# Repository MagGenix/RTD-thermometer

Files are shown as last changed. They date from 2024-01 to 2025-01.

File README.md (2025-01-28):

# RTD-Thermometer
Sreenivas Eadara

## Capabilities
This device can log temperatures down to .03125C using a PT100 probe and takes measurements every 110-120 ms. Measurements are streamed over USB serial (using the RP2040's USB-C port) and stored to a USB-A (plugged in to the USB Host port of the RP2040).

## Summary

This is a data logger built using the following parts from Adafruit:

Microcontroller: Feather RP2040 with USB Type A Host
https://www.adafruit.com/product/5723

Display: OLED FeatherWing
https://www.adafruit.com/product/4650

RTD Amplifier: MAX31865 PT100
https://www.adafruit.com/product/3328

RTD: 3 Wire PT100
https://www.adafruit.com/product/3290

PCB: Mint tin size Perma-Proto
https://www.adafruit.com/product/723

Using these parts just made it easier to finish the project (as opposed to spending time / revisions making my own modules), though there are plenty of other components that could work with modifications to the provided Arduino code.

Assembly involved wiring the MAX31865 to the default SPI pins on the RP2040 USB Host and stacking the OLED on the microcontroller through the perma-proto board. Note that depending on the PT100 probe used, traces may need to be cut and/or jumpers may need to be soldered on the MAX31865 breakout board. Please see Adafruit's instructions for this.

I designed a case to fit the device I built. If it helps, files (STEP and 3MF) are supplied with this repository. I powered the device using a LiPo battery from Adafruit so it could be used for a couple hours away from a charger (i.e. during experiments).

**See the LICENSE file in the CASE folder, which accompanies the STEP and 3MF files for the case, for information on the hardware copyright and licensing**

## Code
This code heavily uses examples and libraries from Adafruit's TinyUSB library and MAX31865 library (as well as the SH110X library for the display)!
It implements a state machine on Core 1 that controls the display and measures temperatures using the MAX31865, while Core 2 and the PIOs are responsible for USB host.

**See the LICENSE file in the FIRMWARE folder, which accompanies the code, for details on the code copyright and licensing.**

## Photos
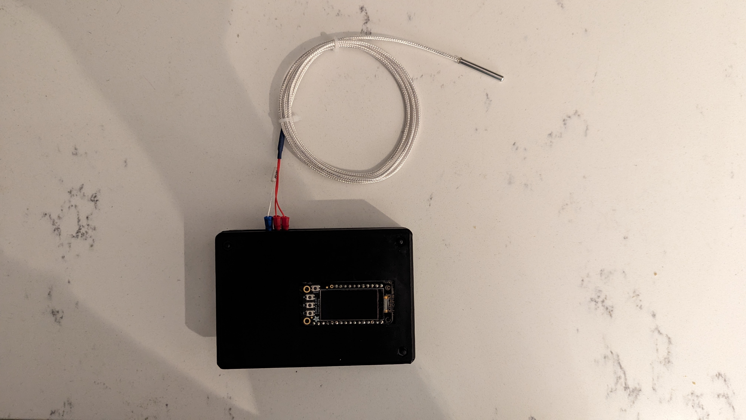
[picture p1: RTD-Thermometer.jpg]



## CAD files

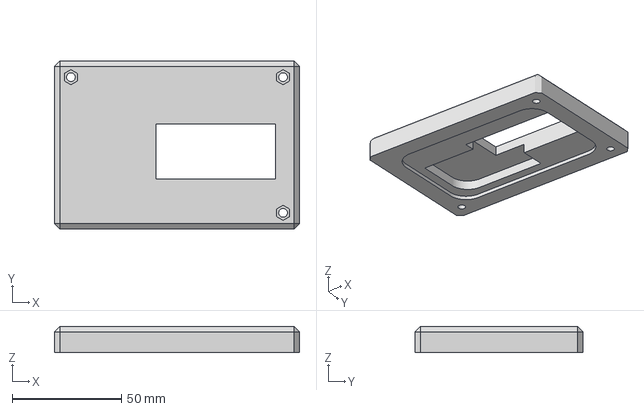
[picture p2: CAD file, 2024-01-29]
CASE/RTD-CASE - TOP.3mf
112.0 x 77.0 x 12.0 mm

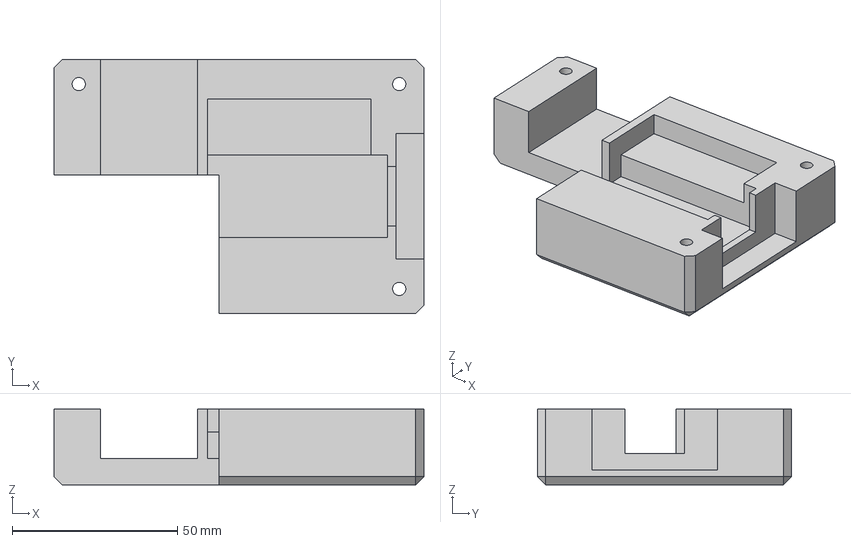
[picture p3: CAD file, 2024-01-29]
CASE/RTD-CASE - BOTTOM.3mf
112.0 x 77.0 x 23.0 mm

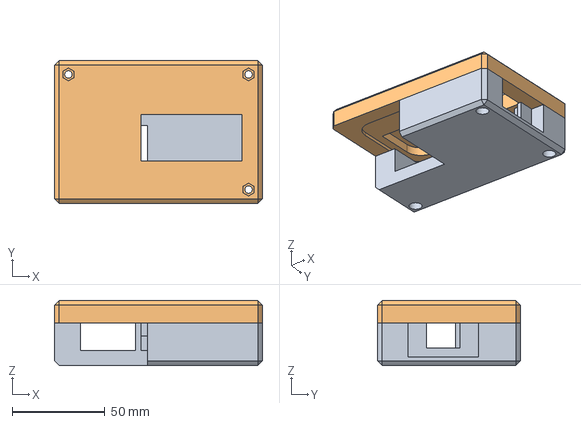
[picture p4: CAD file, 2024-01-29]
CASE/RTD-CASE.step
112.0 x 77.0 x 35.0 mm

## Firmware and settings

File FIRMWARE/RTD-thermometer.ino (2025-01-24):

/*********************************************************************
 Written by Sreenivas Eadara for MagGenix, Inc.
 See notice(s) from code examples or libraries used in this
 software below.
*********************************************************************/
/*********************************************************************
 Adafruit invests time and resources providing this open source code,
 please support Adafruit and open-source hardware by purchasing
 products from Adafruit!

 MIT license, check LICENSE for more information
 Copyright (c) 2019 Ha Thach for Adafruit Industries
 All text above, and the splash screen below must be included in
 any redistribution
*********************************************************************/

#include <SPI.h>
#include <Wire.h>
#include <Adafruit_GFX.h>
#include <Adafruit_SH110X.h>
#include <Adafruit_MAX31865.h>
#include <string.h>

#include "SdFat.h"
#include "msc_data_logger/usbh_helper.h"

Adafruit_SH1107 display = Adafruit_SH1107(64, 128, &Wire);

// OLED FeatherWing buttons map to different pins depending on board:
#define BUTTON_A  9
#define BUTTON_B  6 // used to be 6 SREENI, 8 on other boards
#define BUTTON_C  5 // used to be 5 SREENI, 7 on other boards

Adafruit_MAX31865 thermo = Adafruit_MAX31865(4); // SREENI hardware SPI0 (25, 189, 19, 20) on Feather RP2040. Pass in CS pin only
#define RREF      430.0
#define RNOMINAL  100.0

Adafruit_USBH_MSC_BlockDevice msc_block_dev;

FatVolume fatfs;
File32 f_log;

void setup() {
  Serial.begin(115200);

  pinMode(LED_BUILTIN, OUTPUT);

  delay(250); // wait for the OLED to power up
  display.begin(0x3C, true); // Address 0x3C default
  
  // Show image buffer on the display hardware.
  // Since the buffer is intialized with an Adafruit splashscreen
  // internally, this will display the splashscreen.
  display.display();
  delay(1000);

  // Set display color and orientation
  display.setTextColor(SH110X_WHITE);
  display.setRotation(1);

  // MagGenix Splash
  display.clearDisplay();
  display.setTextSize(3);
  display.print("MAG");
  display.setTextSize(2);
  display.println("GENIX");
  display.drawLine(54, 16, 111, 16, SH110X_WHITE);
  display.println("");
  display.setTextSize(1);
  display.println("SREENIVAS EADARA");
  display.println("FW 1.0.2 2025");
   
  display.display();
  delay(1000);

  // Reset text size
  display.setTextSize(1);

  // Clear the buffer.
  display.clearDisplay();
  display.display();

  pinMode(BUTTON_A, INPUT_PULLUP);
  pinMode(BUTTON_B, INPUT_PULLUP);
  pinMode(BUTTON_C, INPUT_PULLUP);

  thermo.begin(MAX31865_3WIRE);  // set to 2WIRE or 4WIRE as necessary
  
}

volatile int state = 0;
volatile long elapsed = 0;
volatile bool is_mounted = false;

const int LOOP_DURATION = 10;
const long SLEEP_DURATION = 10000;
char CSVNAME[] = "TEMPERATURE_DATA.tsv";

void loop() {
  // USB reactivate on wake
  if (state == -1) {
    if (!digitalRead(BUTTON_A) || !digitalRead(BUTTON_B) || !digitalRead(BUTTON_C)) {
      state = 0;
      elapsed = 0;
      digitalWrite(PIN_5V_EN, PIN_5V_EN_STATE);
      // Only wake from sleep when button released, otherwise next state will be triggered in 10ms
      while (!digitalRead(BUTTON_A) || !digitalRead(BUTTON_B) || !digitalRead(BUTTON_C)) {
        delay(LOOP_DURATION);
      }
    }
  }
  else {
    if(!digitalRead(BUTTON_B) && state == 2){ // only stop recording where one was started
      state = 1;
      elapsed = 0;
      while (!digitalRead(BUTTON_B)) {
        delay(LOOP_DURATION);
      }
      Serial.print("STOP RECORDING:\t");
      Serial.println(millis());
    } 
    else if(!digitalRead(BUTTON_C) && state != 2){ // do not restart recording when one is already running
      state = 2;
      elapsed = 0;
      while (!digitalRead(BUTTON_C)){
        delay(LOOP_DURATION);
      }
      Serial.print("BEGIN RECORDING:\t");
      Serial.println(millis());
      if (is_mounted && !f_log){
        f_log = fatfs.open(CSVNAME, O_WRITE | O_APPEND | O_CREAT);
        Serial.flush();
      }
    }
    else { // state transition logic
      if (elapsed > SLEEP_DURATION){
          state -= 1;
          elapsed = 0;
          if (state == 1) {
            Serial.print("STOP RECORDING:\t");
            Serial.println(millis());
          }
      }
      else {
        elapsed+=LOOP_DURATION; // avoid overflowing elapsed! only increment if < SLEEP_DURATION
      }
    }
  }
  display.clearDisplay();
  display.setCursor(0,0);
  if(state == -1){ // should deactivate USB to save power.
    display.display();
    //fatfs.end();
    digitalWrite(PIN_5V_EN, !PIN_5V_EN_STATE);
    return;
  }
  else if(state == 0){
    display.println("THERMOMETER READY.");
    display.println("");
    display.println("");
  }
  else if(state == 1){
    display.println("RECORDING STOPPED.");
    display.println("");
    display.println("");
    f_log.close();
  }
  else if(state == 2){
    unsigned long time = millis() + 75;
    float temp = getTemp();
    writeTemp(temp, time);
    Serial.printf("%i\t%f\n", time, temp);
    display.println("STARTED RECORDING.");
    display.print("TEMP: ");
    display.println(temp);
    if (is_mounted && f_log) {
      display.println("USB LOGGING ACTIVE.");
    } else {
      display.println("USB LOGGING INACTIVE.");
    }
  }

  display.println("<-- STOP  RECORDING");
  display.println("");
  display.println("<-- START RECORDING");
  display.display();
  
  delay(LOOP_DURATION);
  yield();  
}

float getTemp() {
  return thermo.temperature(RNOMINAL, RREF);
}

void writeTemp(float temp, unsigned long time) {
  if (!is_mounted || !f_log) {
    return;
  }

  digitalWrite(LED_BUILTIN, HIGH);
  f_log.printf("%i\t%f\n", time, temp);
}



//------------- Core1 -------------//
void setup1() {
  // configure pio-usb: defined in usbh_helper.h
  rp2040_configure_pio_usb();

  // run host stack on controller (rhport) 1
  // Note: For rp2040 pico-pio-usb, calling USBHost.begin() on core1 will have most of the
  // host bit-banging processing works done in core1 to free up core0 for other works
  USBHost.begin(1);
}

void loop1() {
  USBHost.task();
}

//--------------------------------------------------------------------+
// TinyUSB Host callbacks
//--------------------------------------------------------------------+
bool write_complete_callback(uint8_t dev_addr, tuh_msc_complete_data_t const *cb_data) {
  (void) dev_addr;
  (void) cb_data;

  // turn off LED after write is complete
  // Note this only marks the usb transfer is complete, device can take longer to actual
  // write data to physical flash
  digitalWrite(LED_BUILTIN, LOW);

  return true;
}

extern "C"
{

// Invoked when device is mounted (configured)
void tuh_mount_cb(uint8_t daddr) {
  (void) daddr;
}

/// Invoked when device is unmounted (bus reset/unplugged)
void tuh_umount_cb(uint8_t daddr) {
  (void) daddr;
}

// Invoked when a device with MassStorage interface is mounted
void tuh_msc_mount_cb(uint8_t dev_addr) {
  // Initialize block device with MSC device address
  msc_block_dev.begin(dev_addr);

  // For simplicity this example only support LUN 0
  msc_block_dev.setActiveLUN(0);
  msc_block_dev.setWriteCompleteCallback(write_complete_callback);
  is_mounted = fatfs.begin(&msc_block_dev);

  if (is_mounted) {
    Serial.println("Mounted USB Device");
  } else {
    Serial.println("Failed to mount mass storage device. Make sure it is formatted as FAT");
  }
}

// Invoked when a device with MassStorage interface is unmounted
void tuh_msc_umount_cb(uint8_t dev_addr) {
  (void) dev_addr;

  // unmount file system
  is_mounted = false;
  fatfs.end();

  // end block device
  msc_block_dev.end();
}

}

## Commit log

2023-10-27 Adding RTD-thermometer Arduino firmware
2023-10-29 Add serial prints and delays
2023-11-29 Now works with reading sensor and displaying value
2023-11-29 USB datalogging and serial printing of data work. Unclear why recording lasts for ~200K ms.
2023-11-29 Disable USB when state -1, enable on exit to save power
2023-11-29 Bugfix: fatfs.end before disabling power to USB
    [RTD-thermometer.ino]
2023-11-29 bugfixes: was polling sensor twice and times were inaccurate. now polling once and calling millis once
    [RTD-thermometer.ino]
2023-12-01 Firmware ver1, resolves USB freezing bug and reports USB status
    [RTD-thermometer.ino]
2023-12-01 additional USB bugfix for sleep
    [RTD-thermometer.ino]
2024-01-29 adding documentation
    [RTD-CASE - BOTTOM.3mf, RTD-CASE - TOP.3mf, RTD-CASE.step]
